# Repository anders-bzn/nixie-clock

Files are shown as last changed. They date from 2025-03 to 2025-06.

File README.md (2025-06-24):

# About the Nixie Clock

This is a clock powered by a Raspberry Pi Zero W. It fetches current time by 
NTP and must be connected to a WiFi network to display the time.

The time is displayed on six IN-14 nixie tubes driven by six 74141. No 
multiplexing! The intensity can be adjusted by PWM.

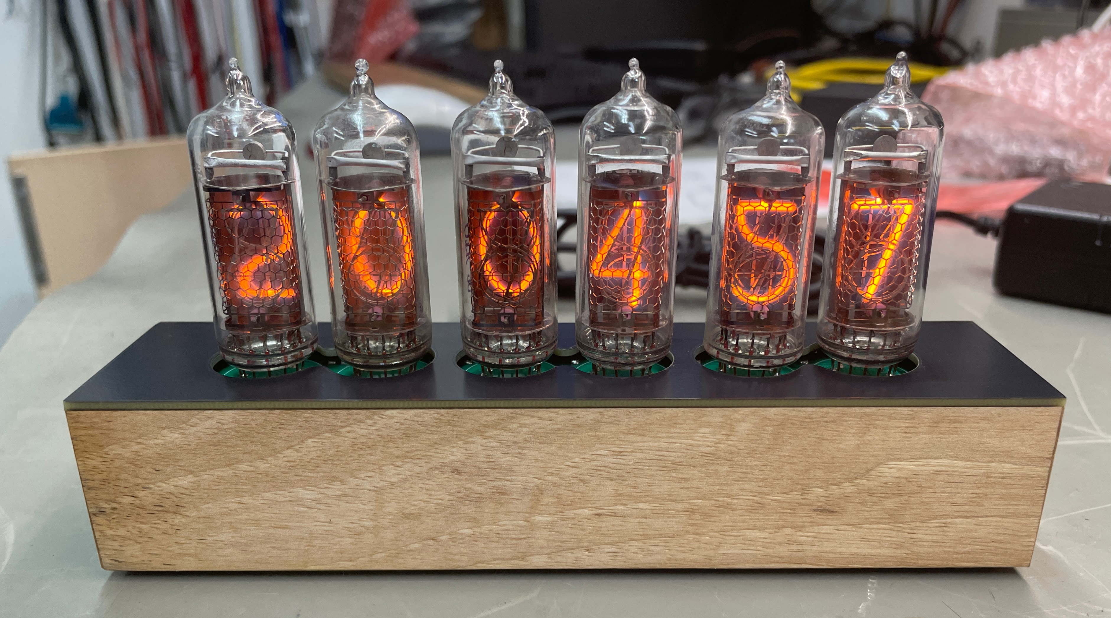
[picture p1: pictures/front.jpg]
Clock front

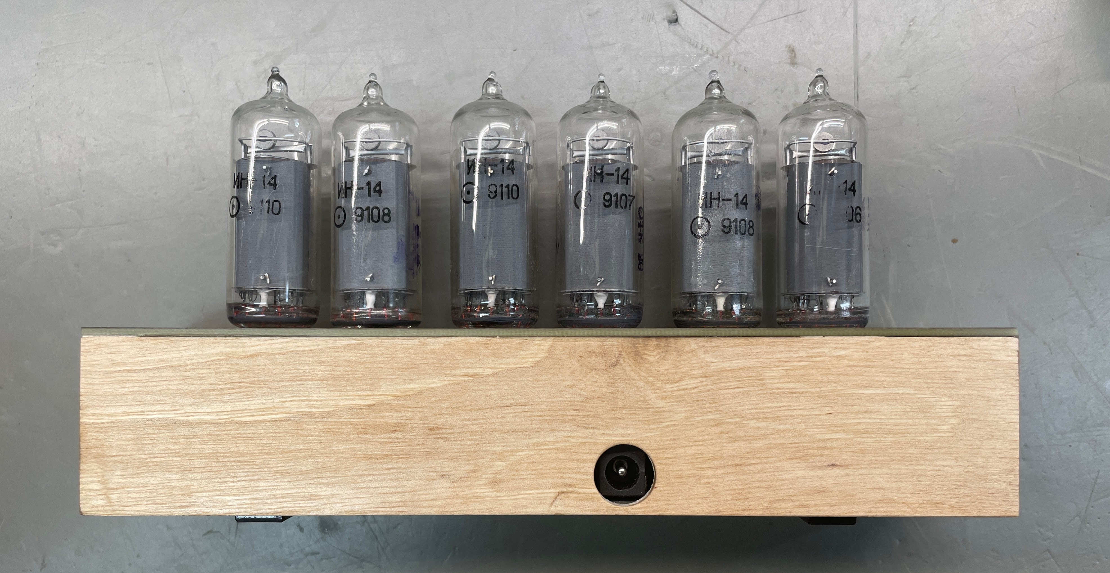
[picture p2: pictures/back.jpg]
Clock back

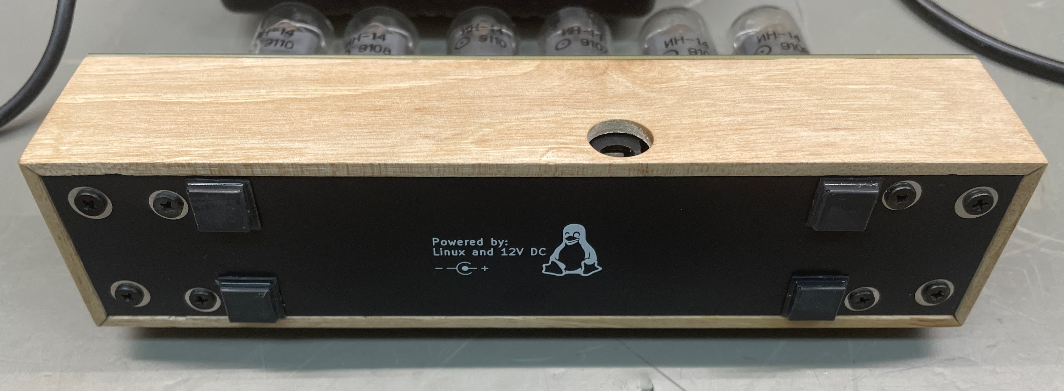
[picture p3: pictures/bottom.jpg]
Clock bottom


## PCB's 
There are in total five PCB's in this project. All boards are drawn with KiCad 8.0.

### Board nixie-bottom
Bottom lid, no electrical function.

### Board nixie-clock
The main board, it hold gpio-expanders and driver IC's for the tubes. It
also connects to the PSU board, Raspberry Pi and the nixie tube board.

### Board nixie-clock-psu
Power supply board, creates 5V DC and 170V DC from 12V DC. The 170V is created by a step up converter built using a MAX1771 IC. The 5V is created by a integrated switched regulator.

### Board nixie-clock-tubes
Upper board on which all tubes are mounted.

### Board nixie-top
Top lid, no electrical function.

### Software
The clocks software is written in Python. It's just a simple poll loop that set the new time on gpio's on the gpio-expanders every time the second changes. It's started as a systemd service at boot time.

To install the software on the Raspberry Pi, copy the [./sw](sw/) folder to the Raspberry Pi and install the software by:

```
$ sudo ./clock-setup.sh
$ sudo reboot
```

NOTE: [./sw/timesyncd.conf](sw/timesyncd.conf) is an example.

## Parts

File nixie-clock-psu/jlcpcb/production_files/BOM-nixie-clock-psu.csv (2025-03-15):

Comment | Designator | Footprint | LCSC | Quantity
R-78B5.0-0.5 | U2 | 78xx-05A |  | 1
MAX1771xSA | U1 | SO-8_3.9x4.9mm_P1.27mm |  | 1
0R10 | R3 | R_1206_3216Metric |  | 1
13k3 | R2 | R_1206_3216Metric |  | 1
1M5 | R1 | R_1206_3216Metric |  | 1
IRF644 | Q1 | TO-263-2 |  | 1
100u | L2 | L_Sunlord_SWPA8040S |  | 1
4u7 | L1 | L_Changjiang_FNR4030S |  | 1
ES2F | D2 | D_SMB |  | 1
1n | C11 | C_0805_2012Metric_Pad1.18x1.45mm_HandSolder |  | 1
100n | C10 | C_0805_2012Metric_Pad1.18x1.45mm_HandSolder |  | 1
100n | C9 | C_0805_2012Metric_Pad1.18x1.45mm_HandSolder |  | 1
100n | C8 | C_0805_2012Metric_Pad1.18x1.45mm_HandSolder |  | 1
10uF/250V | C7 | CP_Elec_10x12.5 |  | 1
330uF/16V | C6 | CP_Elec_6.3x7.7 |  | 1
100uF/10V | C5 | CP_Elec_5x5.3 |  | 1
12V DC | J2 | BarrelJack_GCT_DCJ200-10-A_Horizontal |  | 1
10u | C4 | C_0805_2012Metric_Pad1.18x1.45mm_HandSolder |  | 1
1n | C3 | C_0805_2012Metric_Pad1.18x1.45mm_HandSolder |  | 1
10u | C2 | C_0805_2012Metric_Pad1.18x1.45mm_HandSolder |  | 1
10u | C1 | C_0805_2012Metric_Pad1.18x1.45mm_HandSolder |  | 1
Conn_01x04_Pin | J1 | PinSocket_1x04_P2.54mm_Vertical |  | 1

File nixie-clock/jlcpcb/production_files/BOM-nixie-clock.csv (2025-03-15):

Comment | Designator | Footprint | LCSC | Quantity
1k | R10 | R_0805_2012Metric_Pad1.20x1.40mm_HandSolder |  | 1
1k | R9 | R_1206_3216Metric_Pad1.30x1.75mm_HandSolder |  | 1
220k | R8 | R_1206_3216Metric_Pad1.30x1.75mm_HandSolder |  | 1
PMBTA92 | Q2 | SOT-23 |  | 1
PMBTA42 | Q1 | SOT-23 |  | 1
100n | C9 | C_0805_2012Metric_Pad1.18x1.45mm_HandSolder |  | 1
100n | C8 | C_0805_2012Metric_Pad1.18x1.45mm_HandSolder |  | 1
74141 | U6 | DIP-16_W7.62mm |  | 1
Conn_02x05_Odd_Even | J7 | PinHeader_2x05_P2.00mm_Vertical |  | 1
100n | C5 | C_0805_2012Metric_Pad1.18x1.45mm_HandSolder |  | 1
Conn_02x05_Odd_Even | J9 | PinHeader_2x05_P2.00mm_Vertical |  | 1
Conn_02x05_Odd_Even | J8 | PinHeader_2x05_P2.00mm_Vertical |  | 1
Conn_02x05_Odd_Even | J6 | PinHeader_2x05_P2.00mm_Vertical |  | 1
Conn_02x05_Odd_Even | J5 | PinHeader_2x05_P2.00mm_Vertical |  | 1
Conn_02x02_Odd_Even | J4 | PinHeader_2x02_P2.00mm_Vertical |  | 1
Conn_02x05_Odd_Even | J3 | PinHeader_2x05_P2.00mm_Vertical |  | 1
Conn_01x04_Pin | J2 | PinHeader_1x04_P2.54mm_Vertical |  | 1
TCA9406DC | U4 | SSOP-8_2.95x2.8mm_P0.65mm |  | 1
4k7 | R7 | R_0805_2012Metric_Pad1.20x1.40mm_HandSolder |  | 1
4k7 | R6 | R_0805_2012Metric_Pad1.20x1.40mm_HandSolder |  | 1
MCP23017_SO | U11 | SSOP-28_5.3x10.2mm_P0.65mm |  | 1
74141 | U8 | DIP-16_W7.62mm |  | 1
74141 | U7 | DIP-16_W7.62mm |  | 1
100n | C10 | C_0805_2012Metric_Pad1.18x1.45mm_HandSolder |  | 1
100n | C7 | C_0805_2012Metric_Pad1.18x1.45mm_HandSolder |  | 1
100n | C6 | C_0805_2012Metric_Pad1.18x1.45mm_HandSolder |  | 1
MCP23017_SO | U1 | SSOP-28_5.3x10.2mm_P0.65mm |  | 1
74141 | U5 | DIP-16_W7.62mm |  | 1
74141 | U3 | DIP-16_W7.62mm |  | 1
74141 | U2 | DIP-16_W7.62mm |  | 1
4k7 | R5 | R_0805_2012Metric_Pad1.20x1.40mm_HandSolder |  | 1
4k7 | R4 | R_0805_2012Metric_Pad1.20x1.40mm_HandSolder |  | 1
100n | C4 | C_0805_2012Metric_Pad1.18x1.45mm_HandSolder |  | 1
100n | C3 | C_0805_2012Metric_Pad1.18x1.45mm_HandSolder |  | 1
100n | C2 | C_0805_2012Metric_Pad1.18x1.45mm_HandSolder |  | 1
100n | C1 | C_0805_2012Metric_Pad1.18x1.45mm_HandSolder |  | 1
Raspberry_Pi_2_3 | J1 | Raspberry_Pi_Zero_Socketed_THT_FaceDown_MountingHoles |  | 1

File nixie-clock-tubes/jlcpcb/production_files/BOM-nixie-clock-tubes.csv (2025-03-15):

Comment | Designator | Footprint | LCSC | Quantity
~ | N6 | IN-14 |  | 1
~ | N5 | IN-14 |  | 1
~ | N4 | IN-14 |  | 1
~ | N3 | IN-14 |  | 1
~ | N2 | IN-14 |  | 1
~ | N1 | IN-14 |  | 1
Conn_02x02_Odd_Even | J7 | PinSocket_2x02_P2.00mm_Vertical |  | 1
Conn_02x05_Odd_Even | J6 | PinSocket_2x05_P2.00mm_Vertical |  | 1
Conn_02x05_Odd_Even | J5 | PinSocket_2x05_P2.00mm_Vertical |  | 1
Conn_02x05_Odd_Even | J4 | PinSocket_2x05_P2.00mm_Vertical |  | 1
Conn_02x05_Odd_Even | J3 | PinSocket_2x05_P2.00mm_Vertical |  | 1
Conn_02x05_Odd_Even | J2 | PinSocket_2x05_P2.00mm_Vertical |  | 1
Conn_02x05_Odd_Even | J1 | PinSocket_2x05_P2.00mm_Vertical |  | 1
2k2 | R6 | R_1206_3216Metric |  | 1
2k2 | R5 | R_1206_3216Metric |  | 1
2k2 | R4 | R_1206_3216Metric |  | 1
2k2 | R3 | R_1206_3216Metric |  | 1
2k2 | R2 | R_1206_3216Metric |  | 1
2k2 | R1 | R_1206_3216Metric |  | 1

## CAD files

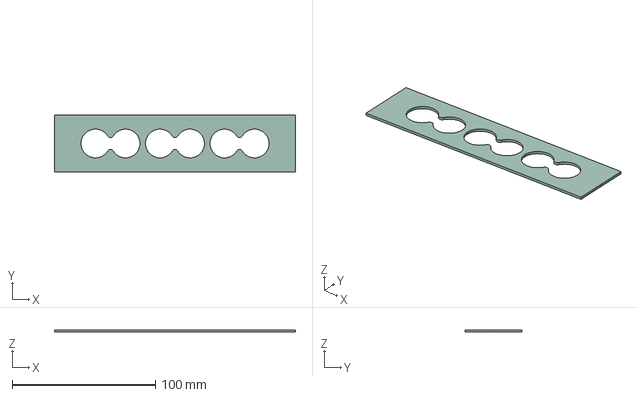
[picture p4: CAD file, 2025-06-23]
nixie-top/nixie-top.step
168.0 x 40.0 x 1.60 mm

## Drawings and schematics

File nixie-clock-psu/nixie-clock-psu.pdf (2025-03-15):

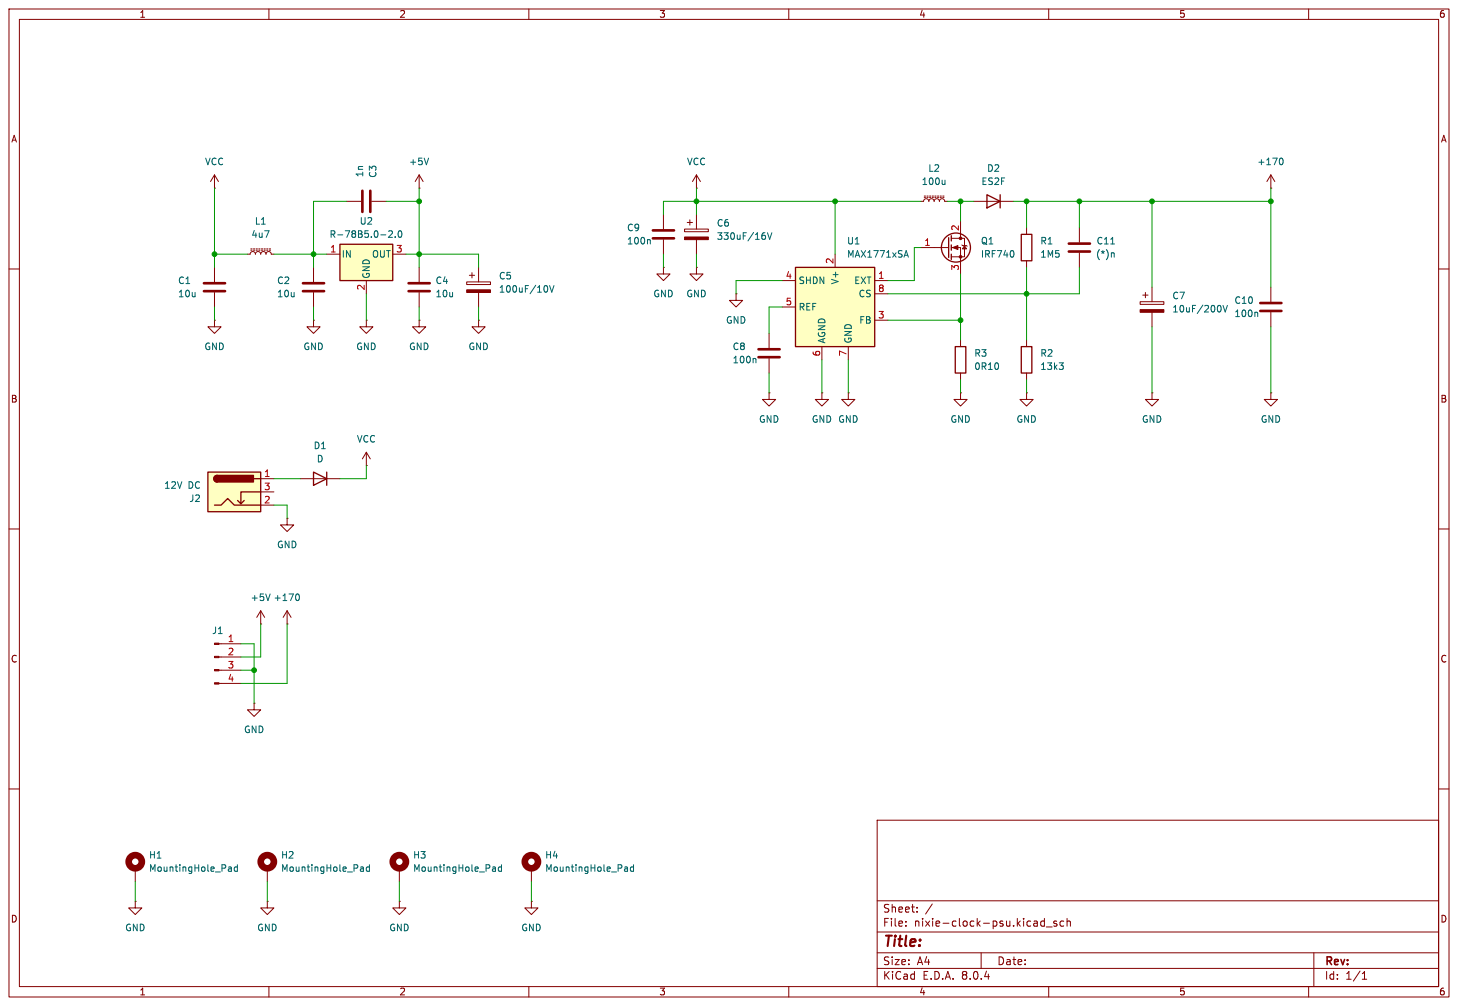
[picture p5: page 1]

2 FB 3 SHDN 4 REF 5 AGND

Id: 1/1 Title: File: nixie-clock-psu.kicad_sch Sheet: /

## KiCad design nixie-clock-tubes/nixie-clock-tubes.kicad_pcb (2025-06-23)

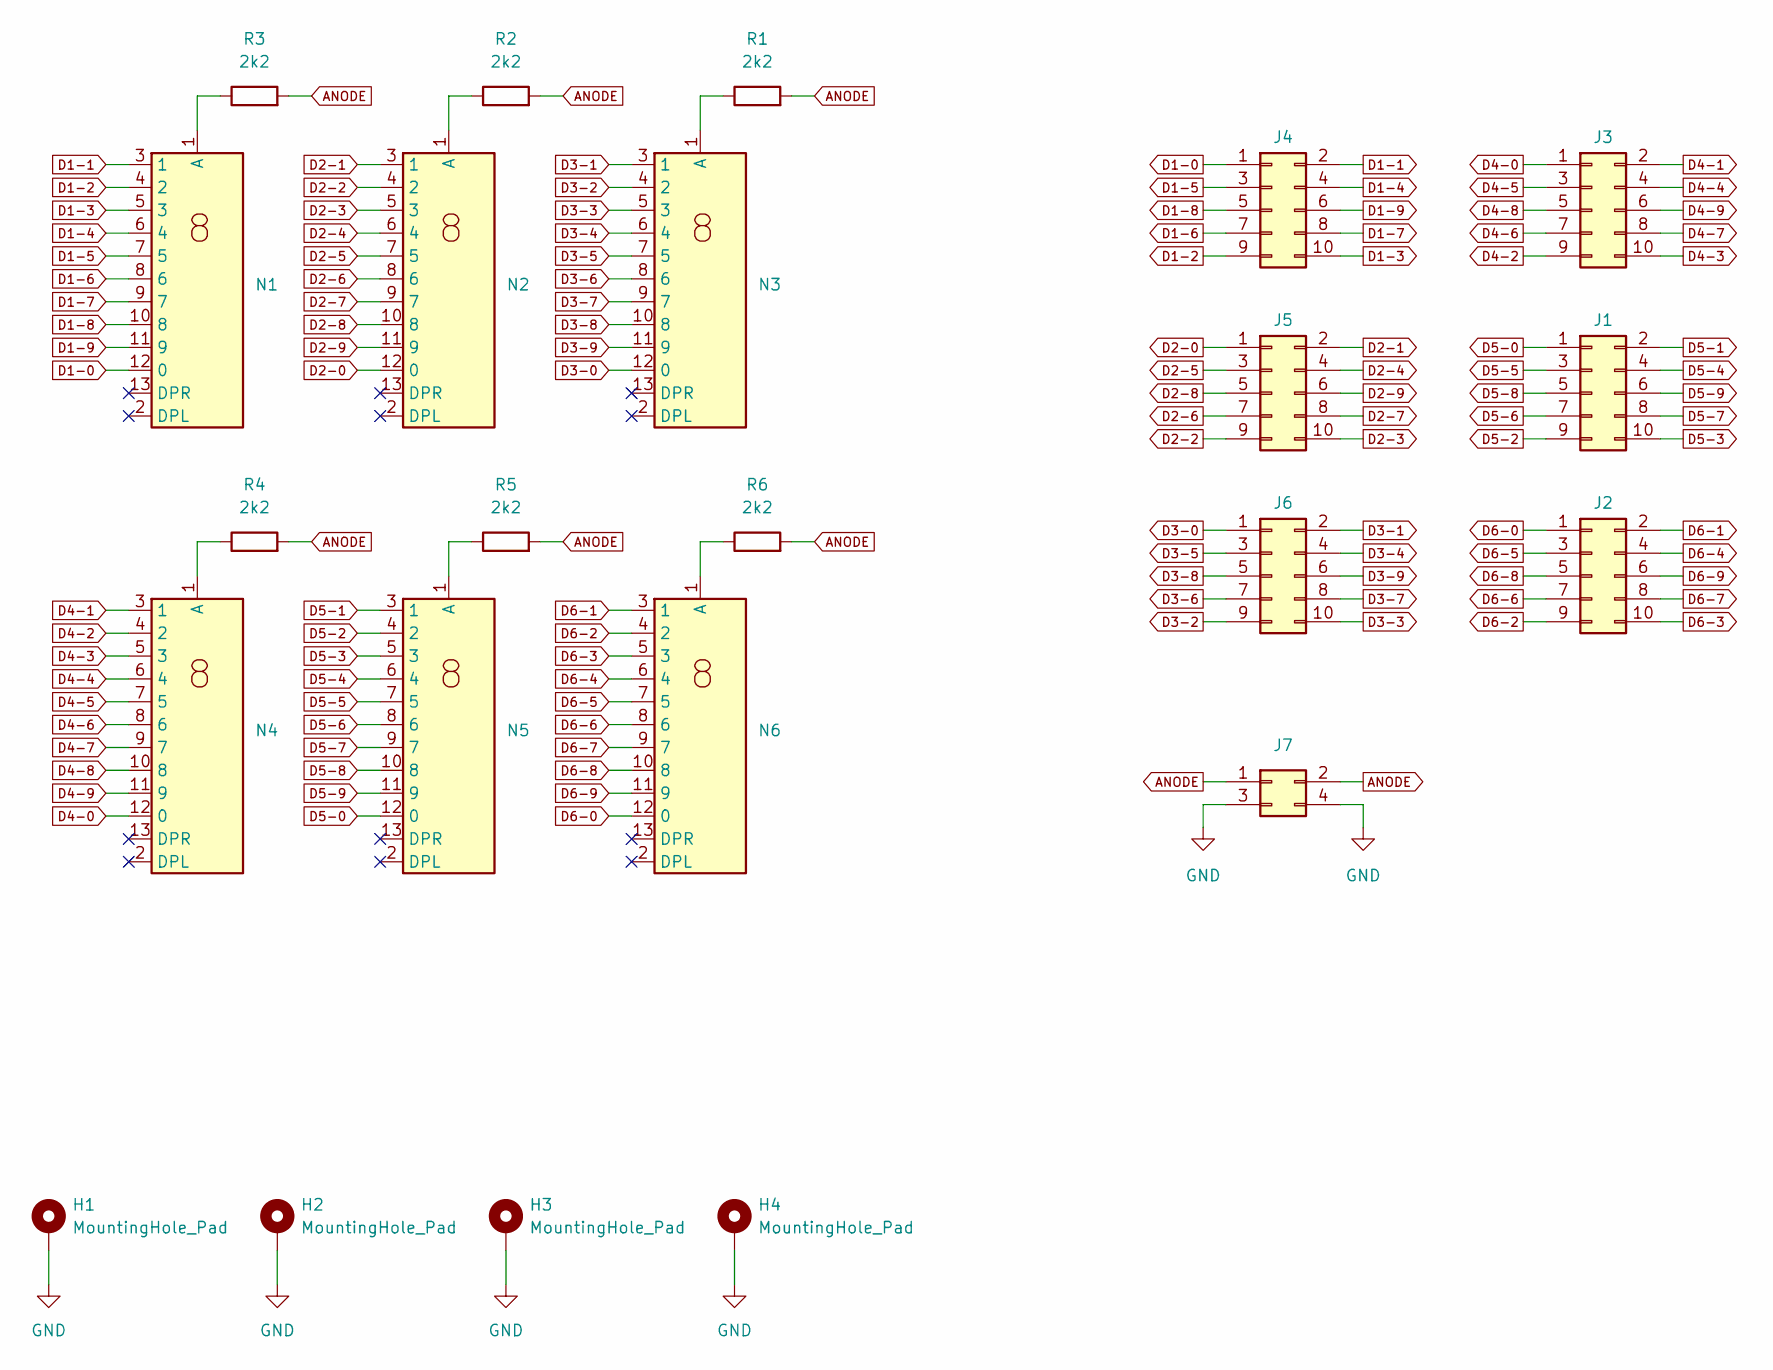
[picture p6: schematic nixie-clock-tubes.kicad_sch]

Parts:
H1, H2, H3, H4: MountingHole_Pad; MountingHole_2.7mm_M2.5_DIN965_Pad
J1, J2, J3, J4, J5, J6: Conn_02x05_Odd_Even; PinSocket_2x05_P2.00mm_Vertical
J7: Conn_02x02_Odd_Even; PinSocket_2x02_P2.00mm_Vertical
N1, N2, N3, N4, N5, N6: IN-14
R1, R2, R3, R4, R5, R6: 2k2; R_1206_3216Metric

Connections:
ANODE: J7.1, J7.2, R1.2, R2.2, R3.2, R4.2, R5.2, R6.2
D1-0: J4.1, N1.12 (0)
D1-1: J4.2, N1.3 (1)
D1-2: J4.9, N1.4 (2)
D1-3: J4.10, N1.5 (3)
D1-4: J4.4, N1.6 (4)
D1-5: J4.3, N1.7 (5)
D1-6: J4.7, N1.8 (6)
D1-7: J4.8, N1.9 (7)
D1-8: J4.5, N1.10 (8)
D1-9: J4.6, N1.11 (9)
D2-0: J5.1, N2.12 (0)
D2-1: J5.2, N2.3 (1)
D2-2: J5.9, N2.4 (2)
D2-3: J5.10, N2.5 (3)
D2-4: J5.4, N2.6 (4)
D2-5: J5.3, N2.7 (5)
D2-6: J5.7, N2.8 (6)
D2-7: J5.8, N2.9 (7)
D2-8: J5.5, N2.10 (8)
D2-9: J5.6, N2.11 (9)
D3-0: J6.1, N3.12 (0)
D3-1: J6.2, N3.3 (1)
D3-2: J6.9, N3.4 (2)
D3-3: J6.10, N3.5 (3)
D3-4: J6.4, N3.6 (4)
D3-5: J6.3, N3.7 (5)
D3-6: J6.7, N3.8 (6)
D3-7: J6.8, N3.9 (7)
D3-8: J6.5, N3.10 (8)
D3-9: J6.6, N3.11 (9)
D4-0: J3.1, N4.12 (0)
D4-1: J3.2, N4.3 (1)
D4-2: J3.9, N4.4 (2)
D4-3: J3.10, N4.5 (3)
D4-4: J3.4, N4.6 (4)
D4-5: J3.3, N4.7 (5)
D4-6: J3.7, N4.8 (6)
D4-7: J3.8, N4.9 (7)
D4-8: J3.5, N4.10 (8)
D4-9: J3.6, N4.11 (9)
D5-0: J1.1, N5.12 (0)
D5-1: J1.2, N5.3 (1)
D5-2: J1.9, N5.4 (2)
D5-3: J1.10, N5.5 (3)
D5-4: J1.4, N5.6 (4)
D5-5: J1.3, N5.7 (5)
D5-6: J1.7, N5.8 (6)
D5-7: J1.8, N5.9 (7)
D5-8: J1.5, N5.10 (8)
D5-9: J1.6, N5.11 (9)
D6-0: J2.1, N6.12 (0)
D6-1: J2.2, N6.3 (1)
D6-2: J2.9, N6.4 (2)
D6-3: J2.10, N6.5 (3)
D6-4: J2.4, N6.6 (4)
D6-5: J2.3, N6.7 (5)
D6-6: J2.7, N6.8 (6)
D6-7: J2.8, N6.9 (7)
D6-8: J2.5, N6.10 (8)
D6-9: J2.6, N6.11 (9)
GND: H1.1, H2.1, H3.1, H4.1, J7.3, J7.4
unnamed: N1.1 (A), R3.1
unnamed: N2.1 (A), R2.1
unnamed: N3.1 (A), R1.1
unnamed: N4.1 (A), R4.1
unnamed: N5.1 (A), R5.1
unnamed: N6.1 (A), R6.1

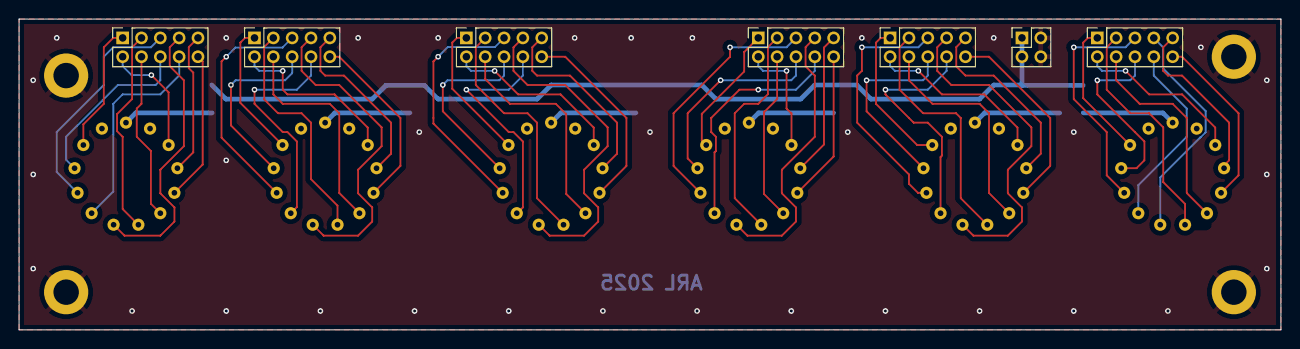
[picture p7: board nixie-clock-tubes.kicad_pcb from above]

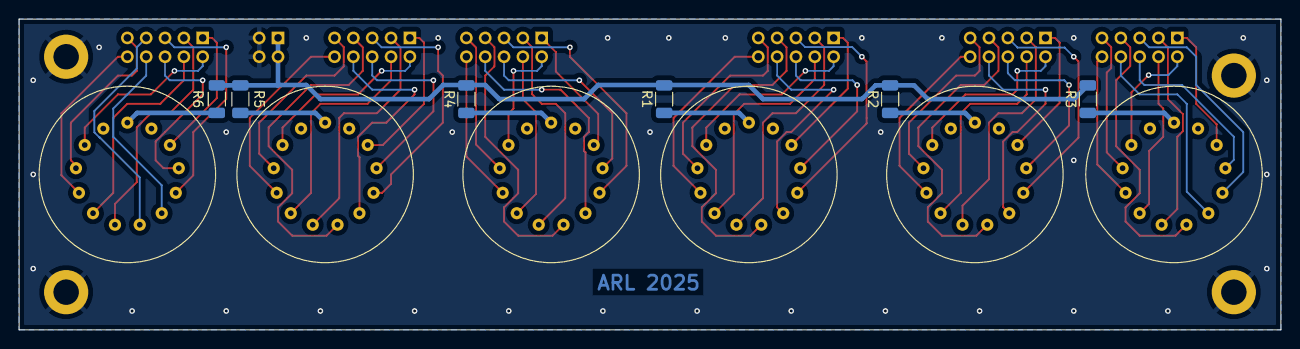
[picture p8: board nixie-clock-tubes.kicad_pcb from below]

Board: 2 copper layers, 134.0 x 33.0 mm, 23 parts (12 on the bottom side), 68 nets.

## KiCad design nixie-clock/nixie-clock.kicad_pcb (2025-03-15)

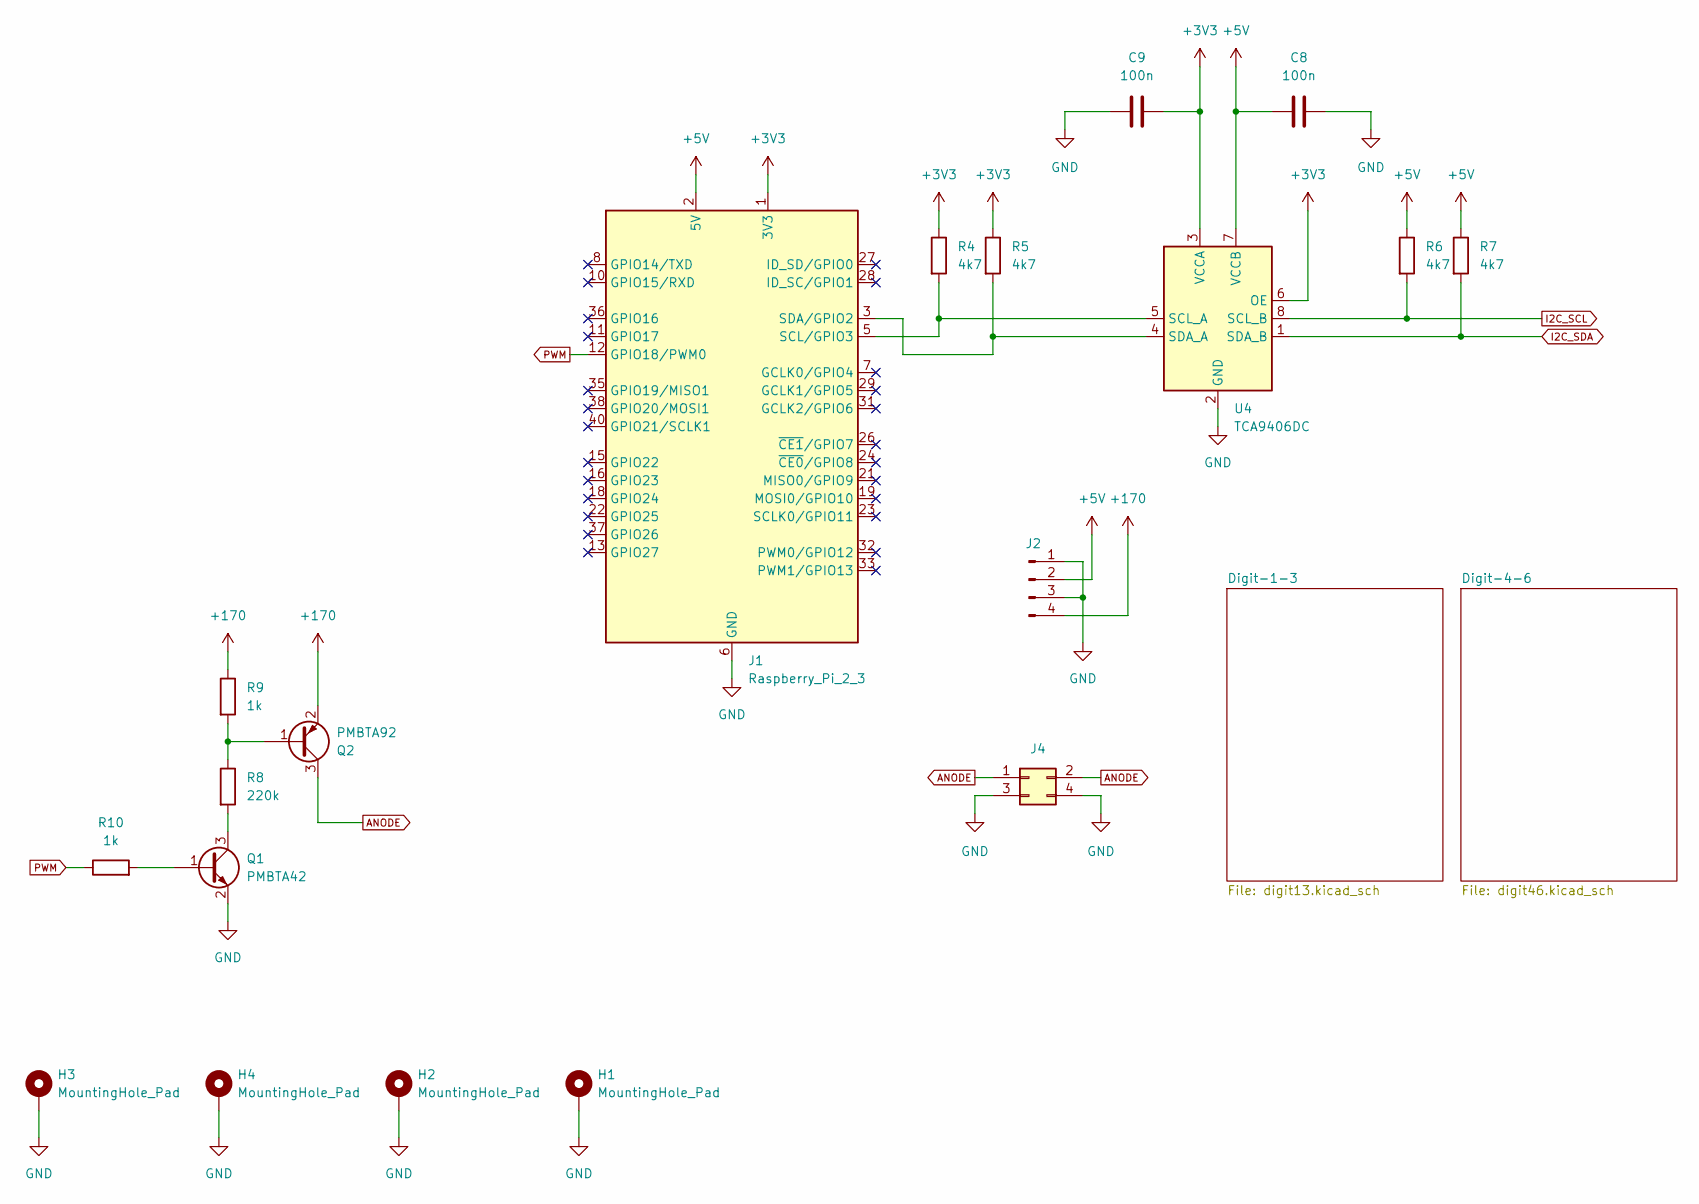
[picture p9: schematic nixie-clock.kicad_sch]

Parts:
C8, C9: 100n; C_0805_2012Metric_Pad1.18x1.45mm_HandSolder
H1, H2, H3, H4: MountingHole_Pad; MountingHole_2.7mm_M2.5_DIN965_Pad
J1: Raspberry_Pi_2_3; Raspberry_Pi_Zero_Socketed_THT_FaceDown_MountingHoles
J2: Conn_01x04_Pin; PinHeader_1x04_P2.54mm_Vertical
J4: Conn_02x02_Odd_Even; PinHeader_2x02_P2.00mm_Vertical
Q1: PMBTA42; SOT-23
Q2: PMBTA92; SOT-23
R4, R5, R6, R7: 4k7; R_0805_2012Metric_Pad1.20x1.40mm_HandSolder
R8: 220k; R_1206_3216Metric_Pad1.30x1.75mm_HandSolder
R9: 1k; R_1206_3216Metric_Pad1.30x1.75mm_HandSolder
R10: 1k; R_0805_2012Metric_Pad1.20x1.40mm_HandSolder
U4: TCA9406DC; SSOP-8_2.95x2.8mm_P0.65mm

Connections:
+3V3: C9.1, J1.1 (3V3), J1.17 (3V3), R4.1, R5.1, U4.3 (VCCA), U4.6 (OE)
+5V: C8.1, J1.2 (5V), J1.4 (5V), J2.2, R6.1, R7.1, U4.7 (VCCB); also elsewhere on the board
+170: J2.4, Q2.2 (E), R9.1
ANODE: J4.1, J4.2, Q2.3 (C)
GND: C8.2, C9.2, H1.1, H2.1, H3.1, H4.1, J1.6 (GND), J1.9 (GND), J1.14 (GND), J1.20 (GND), J1.25 (GND), J1.30 (GND), J1.34 (GND), J1.39 (GND), J2.1, J2.3, J4.3, J4.4, Q1.2 (E), U4.2 (GND); also elsewhere on the board
I2C_SCL: R6.2, U4.8 (SCL_B); also elsewhere on the board
I2C_SDA: R7.2, U4.1 (SDA_B); also elsewhere on the board
unnamed: J1.5 (SCL/GPIO3), R4.2, U4.5 (SCL_A)
unnamed: J1.3 (SDA/GPIO2), R5.2, U4.4 (SDA_A)
unnamed: Q1.1 (B), R10.2
unnamed: Q1.3 (C), R8.2
unnamed: Q2.1 (B), R8.1, R9.2
PWM: J1.12 (GPIO18/PWM0), R10.1

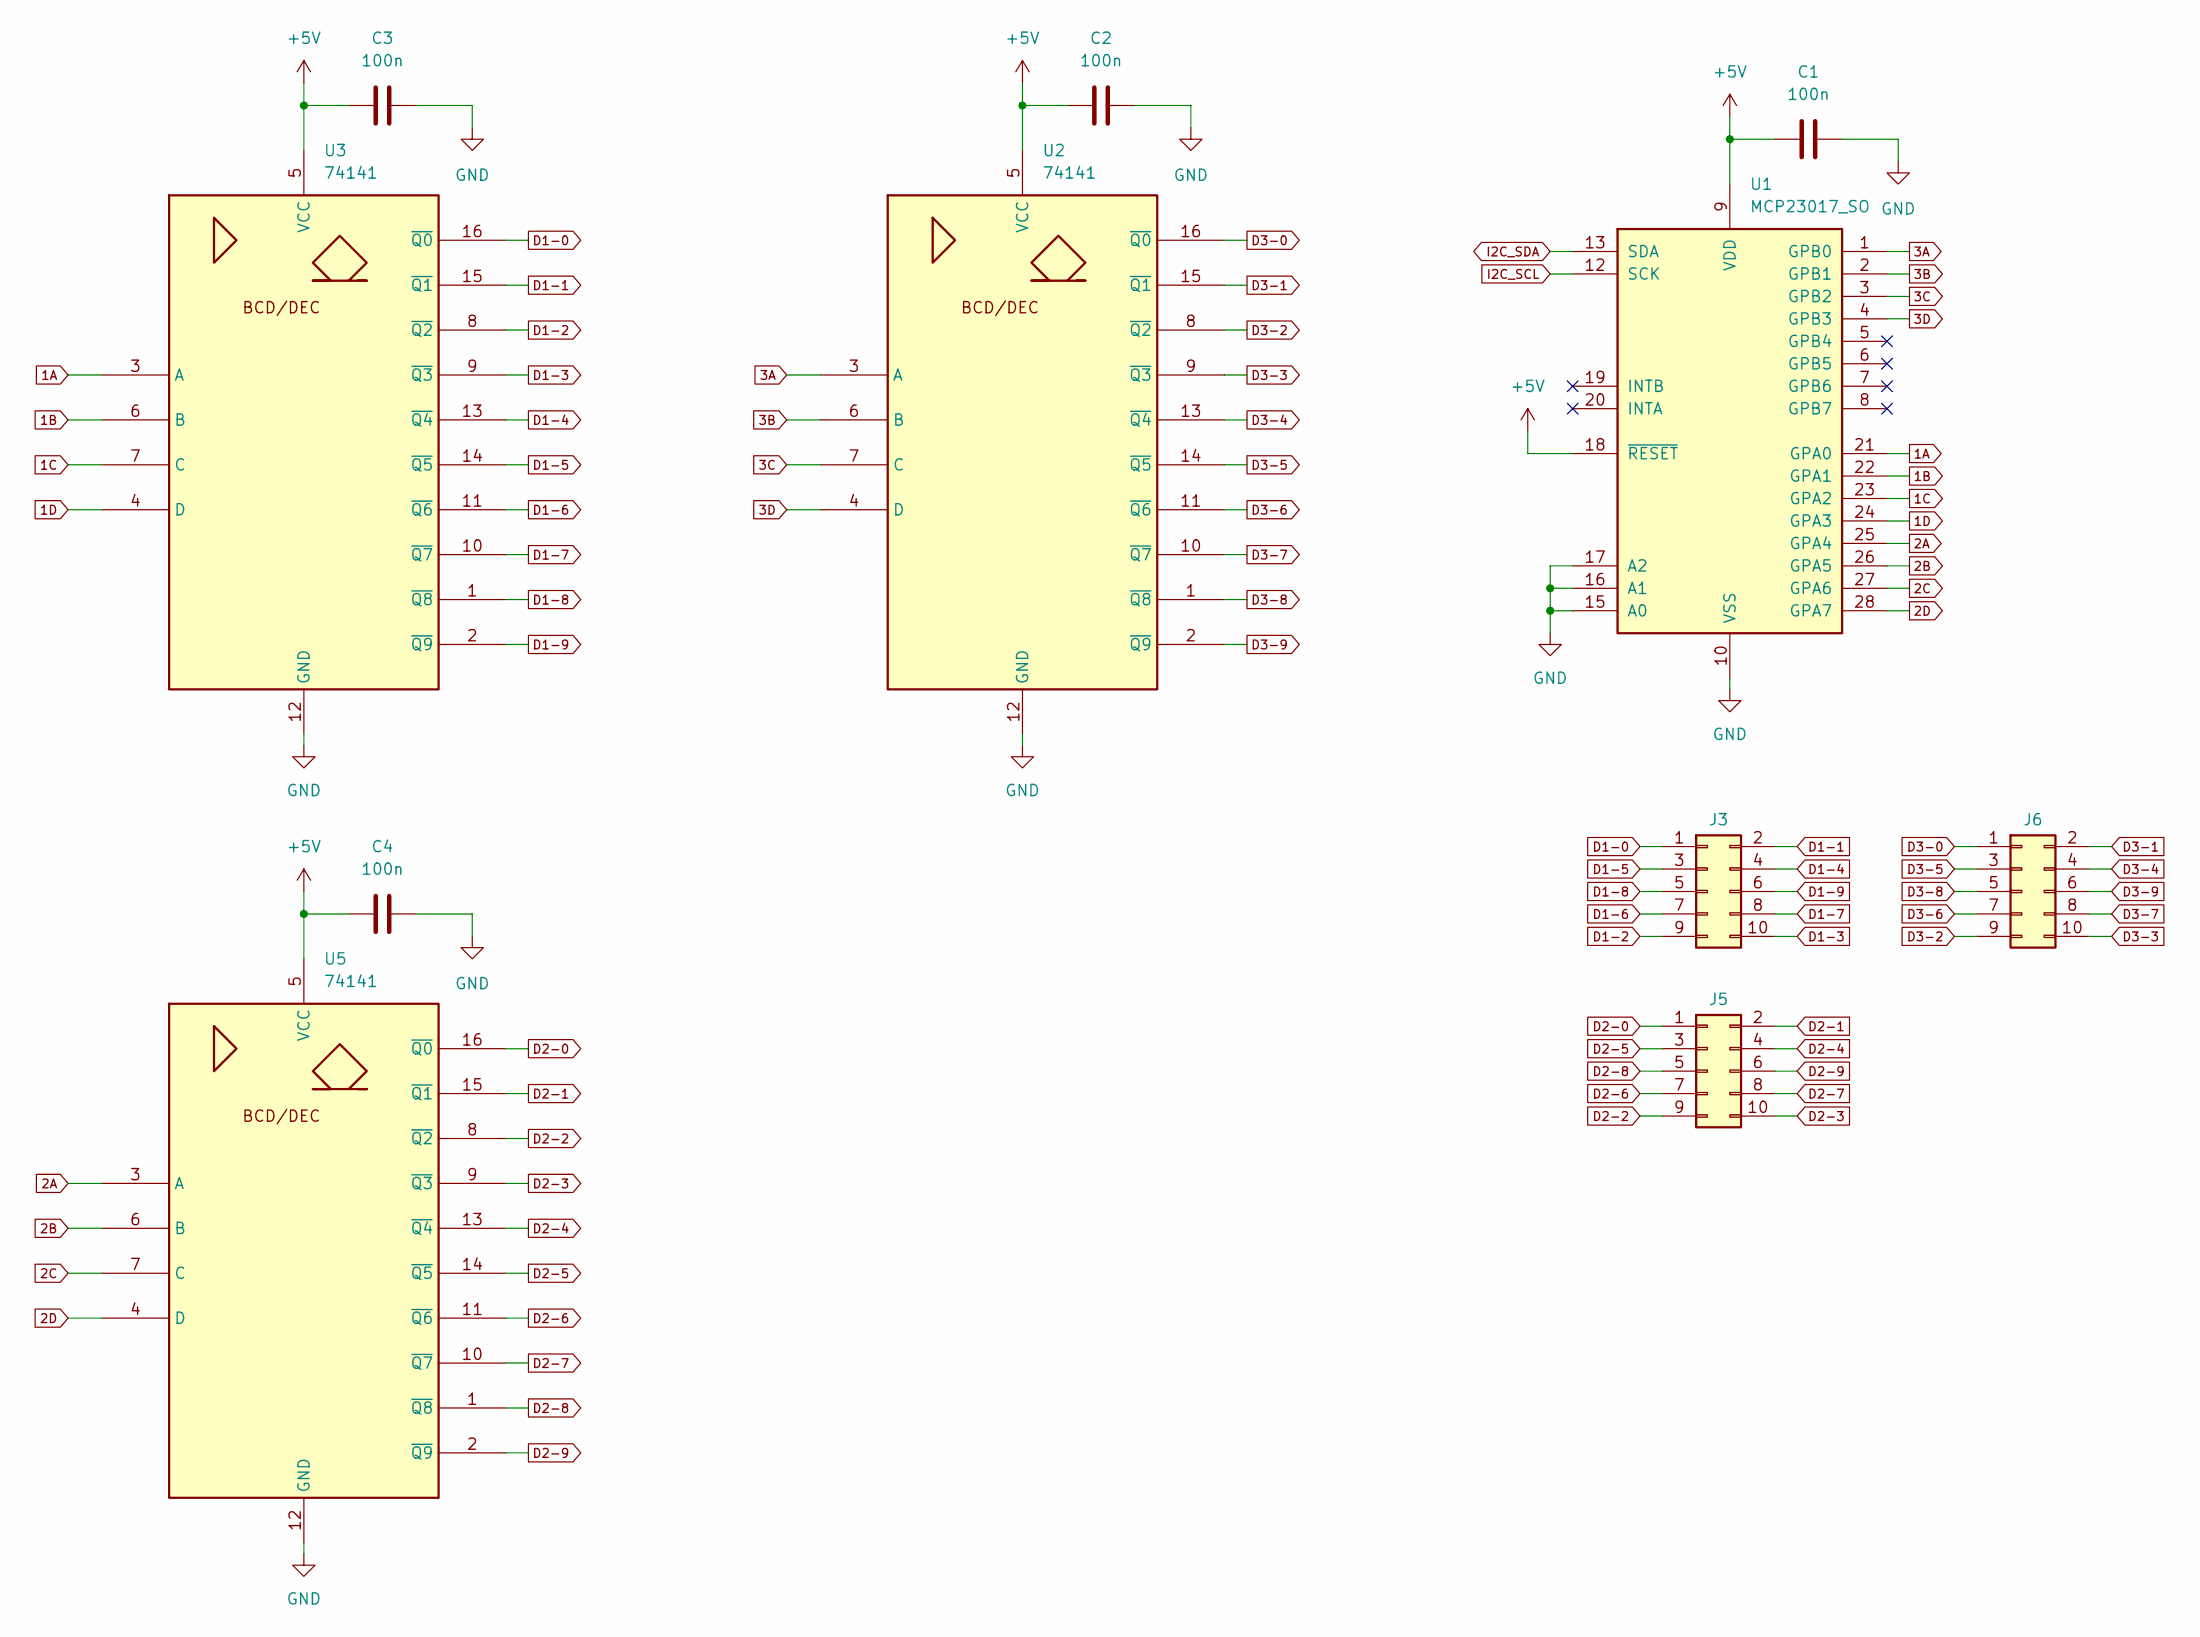
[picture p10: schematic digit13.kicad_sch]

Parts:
C1, C2, C3, C4: 100n; C_0805_2012Metric_Pad1.18x1.45mm_HandSolder
J3, J5, J6: Conn_02x05_Odd_Even; PinHeader_2x05_P2.00mm_Vertical
U1: MCP23017_SO; SSOP-28_5.3x10.2mm_P0.65mm
U2, U3, U5: 74141; DIP-16_W7.62mm

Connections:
1A: U1.21 (GPA0), U3.3 (A)
1B: U1.22 (GPA1), U3.6 (B)
1C: U1.23 (GPA2), U3.7 (C)
1D: U1.24 (GPA3), U3.4 (D)
2A: U1.25 (GPA4), U5.3 (A)
2B: U1.26 (GPA5), U5.6 (B)
2C: U1.27 (GPA6), U5.7 (C)
2D: U1.28 (GPA7), U5.4 (D)
3A: U1.1 (GPB0), U2.3 (A)
3B: U1.2 (GPB1), U2.6 (B)
3C: U1.3 (GPB2), U2.7 (C)
3D: U1.4 (GPB3), U2.4 (D)
+5V: C1.1, C2.1, C3.1, C4.1, U1.9 (VDD), U1.18 (~RESET), U2.5 (VCC), U3.5 (VCC), U5.5 (VCC); also elsewhere on the board
D1-0: J3.1, U3.16 (~Q0)
D1-1: J3.2, U3.15 (~Q1)
D1-2: J3.9, U3.8 (~Q2)
D1-3: J3.10, U3.9 (~Q3)
D1-4: J3.4, U3.13 (~Q4)
D1-5: J3.3, U3.14 (~Q5)
D1-6: J3.7, U3.11 (~Q6)
D1-7: J3.8, U3.10 (~Q7)
D1-8: J3.5, U3.1 (~Q8)
D1-9: J3.6, U3.2 (~Q9)
D2-0: J5.1, U5.16 (~Q0)
D2-1: J5.2, U5.15 (~Q1)
D2-2: J5.9, U5.8 (~Q2)
D2-3: J5.10, U5.9 (~Q3)
D2-4: J5.4, U5.13 (~Q4)
D2-5: J5.3, U5.14 (~Q5)
D2-6: J5.7, U5.11 (~Q6)
D2-7: J5.8, U5.10 (~Q7)
D2-8: J5.5, U5.1 (~Q8)
D2-9: J5.6, U5.2 (~Q9)
D3-0: J6.1, U2.16 (~Q0)
D3-1: J6.2, U2.15 (~Q1)
D3-2: J6.9, U2.8 (~Q2)
D3-3: J6.10, U2.9 (~Q3)
D3-4: J6.4, U2.13 (~Q4)
D3-5: J6.3, U2.14 (~Q5)
D3-6: J6.7, U2.11 (~Q6)
D3-7: J6.8, U2.10 (~Q7)
D3-8: J6.5, U2.1 (~Q8)
D3-9: J6.6, U2.2 (~Q9)
GND: C1.2, C2.2, C3.2, C4.2, U1.10 (VSS), U1.15 (A0), U1.16 (A1), U1.17 (A2), U2.12 (GND), U3.12 (GND), U5.12 (GND); also elsewhere on the board
I2C_SCL: U1.12 (SCK); also elsewhere on the board
I2C_SDA: U1.13 (SDA); also elsewhere on the board

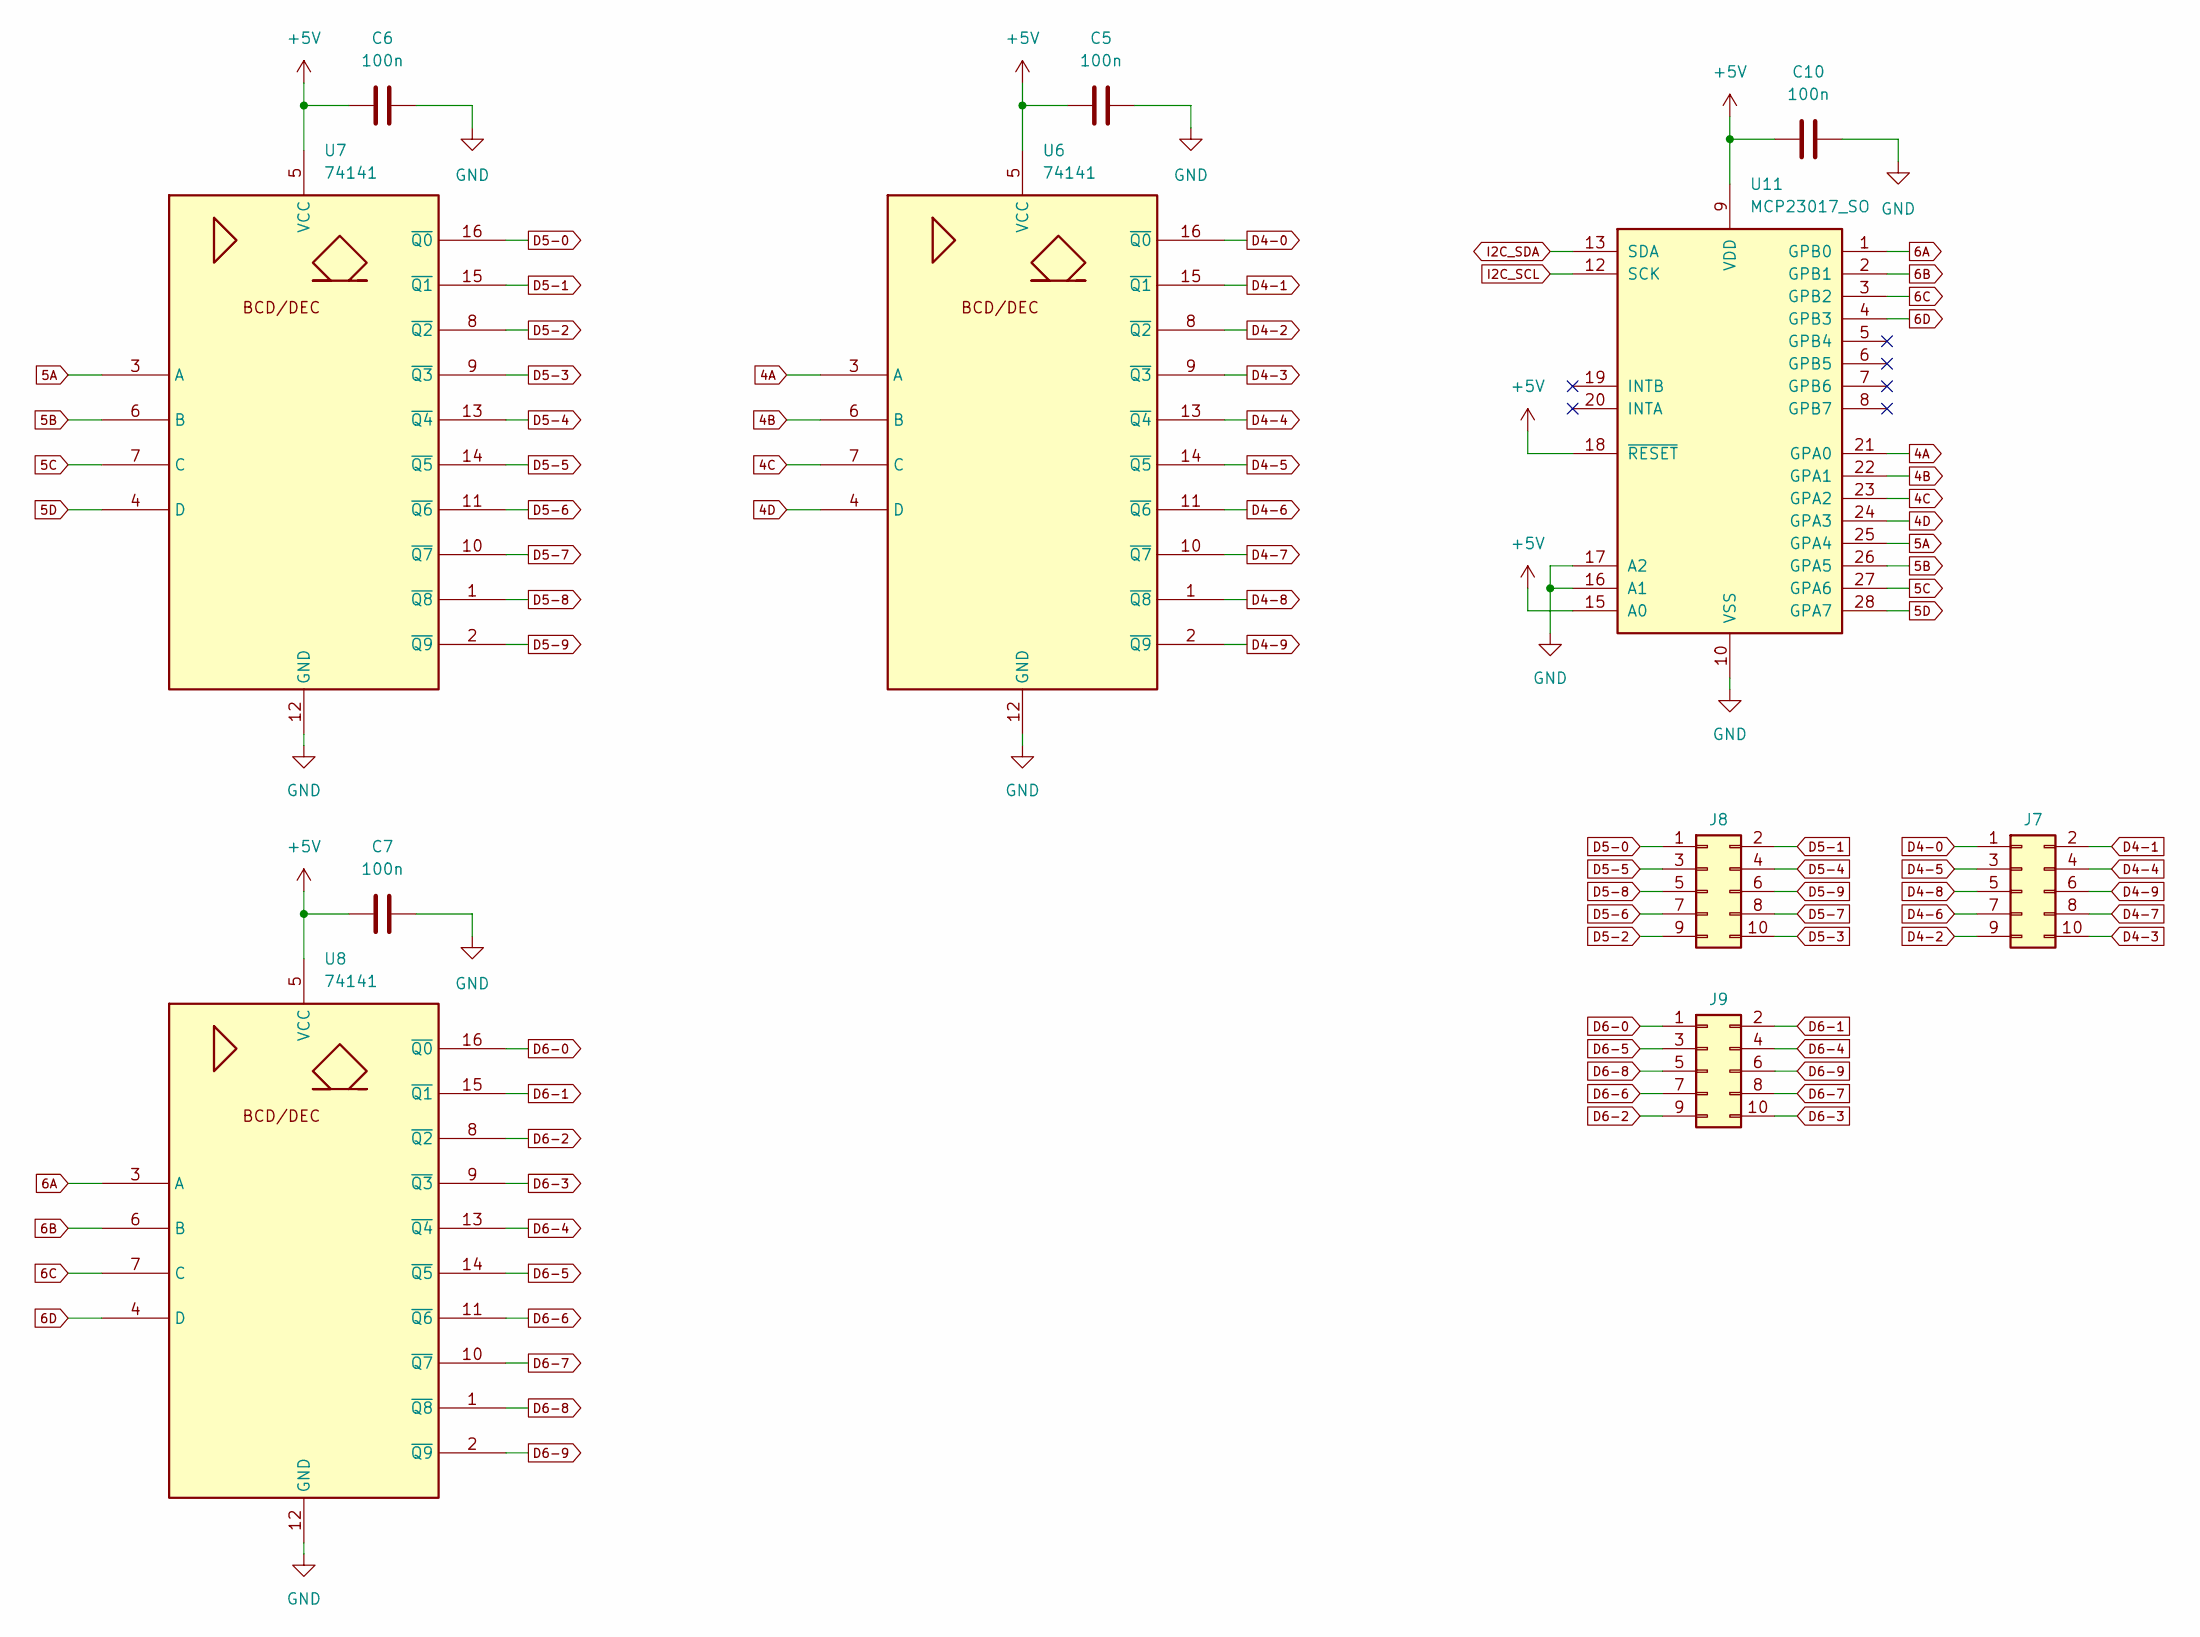
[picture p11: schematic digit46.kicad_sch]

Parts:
C5, C6, C7, C10: 100n; C_0805_2012Metric_Pad1.18x1.45mm_HandSolder
J7, J8, J9: Conn_02x05_Odd_Even; PinHeader_2x05_P2.00mm_Vertical
U6, U7, U8: 74141; DIP-16_W7.62mm
U11: MCP23017_SO; SSOP-28_5.3x10.2mm_P0.65mm

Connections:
4A: U6.3 (A), U11.21 (GPA0)
4B: U6.6 (B), U11.22 (GPA1)
4C: U6.7 (C), U11.23 (GPA2)
4D: U6.4 (D), U11.24 (GPA3)
5A: U7.3 (A), U11.25 (GPA4)
5B: U7.6 (B), U11.26 (GPA5)
5C: U7.7 (C), U11.27 (GPA6)
5D: U7.4 (D), U11.28 (GPA7)
6A: U8.3 (A), U11.1 (GPB0)
6B: U8.6 (B), U11.2 (GPB1)
6C: U8.7 (C), U11.3 (GPB2)
6D: U8.4 (D), U11.4 (GPB3)
+5V: C5.1, C6.1, C7.1, C10.1, U6.5 (VCC), U7.5 (VCC), U8.5 (VCC), U11.9 (VDD), U11.15 (A0), U11.18 (~RESET); also elsewhere on the board
D4-0: J7.1, U6.16 (~Q0)
D4-1: J7.2, U6.15 (~Q1)
D4-2: J7.9, U6.8 (~Q2)
D4-3: J7.10, U6.9 (~Q3)
D4-4: J7.4, U6.13 (~Q4)
D4-5: J7.3, U6.14 (~Q5)
D4-6: J7.7, U6.11 (~Q6)
D4-7: J7.8, U6.10 (~Q7)
D4-8: J7.5, U6.1 (~Q8)
D4-9: J7.6, U6.2 (~Q9)
D5-0: J8.1, U7.16 (~Q0)
D5-1: J8.2, U7.15 (~Q1)
D5-2: J8.9, U7.8 (~Q2)
D5-3: J8.10, U7.9 (~Q3)
D5-4: J8.4, U7.13 (~Q4)
D5-5: J8.3, U7.14 (~Q5)
D5-6: J8.7, U7.11 (~Q6)
D5-7: J8.8, U7.10 (~Q7)
D5-8: J8.5, U7.1 (~Q8)
D5-9: J8.6, U7.2 (~Q9)
D6-0: J9.1, U8.16 (~Q0)
D6-1: J9.2, U8.15 (~Q1)
D6-2: J9.9, U8.8 (~Q2)
D6-3: J9.10, U8.9 (~Q3)
D6-4: J9.4, U8.13 (~Q4)
D6-5: J9.3, U8.14 (~Q5)
D6-6: J9.7, U8.11 (~Q6)
D6-7: J9.8, U8.10 (~Q7)
D6-8: J9.5, U8.1 (~Q8)
D6-9: J9.6, U8.2 (~Q9)
GND: C5.2, C6.2, C7.2, C10.2, U6.12 (GND), U7.12 (GND), U8.12 (GND), U11.10 (VSS), U11.16 (A1), U11.17 (A2); also elsewhere on the board
I2C_SCL: U11.12 (SCK); also elsewhere on the board
I2C_SDA: U11.13 (SDA); also elsewhere on the board

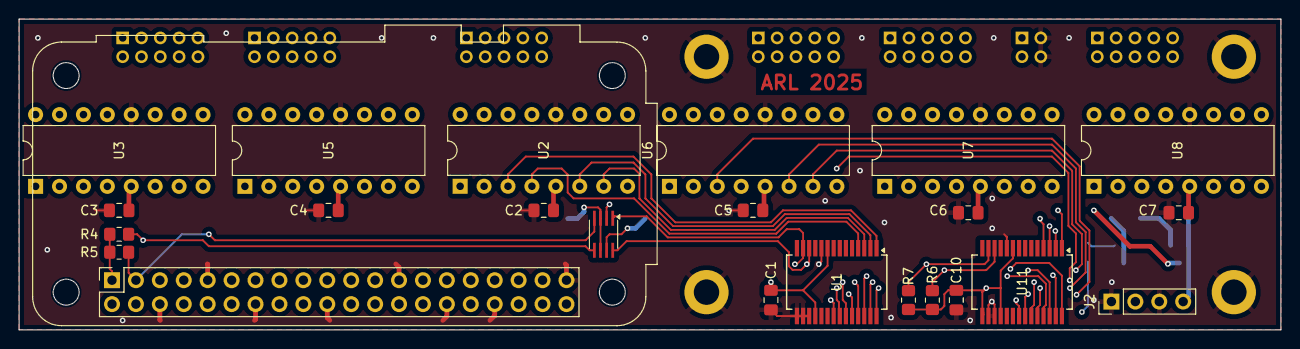
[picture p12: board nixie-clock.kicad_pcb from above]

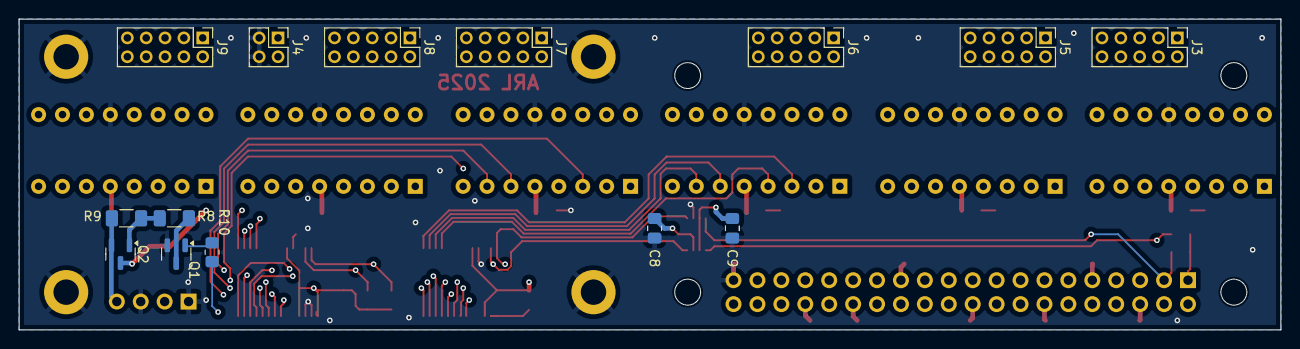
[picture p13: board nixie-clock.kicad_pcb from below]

Board: 4 copper layers, 134.0 x 33.0 mm, 41 parts (14 on the bottom side), 97 nets.

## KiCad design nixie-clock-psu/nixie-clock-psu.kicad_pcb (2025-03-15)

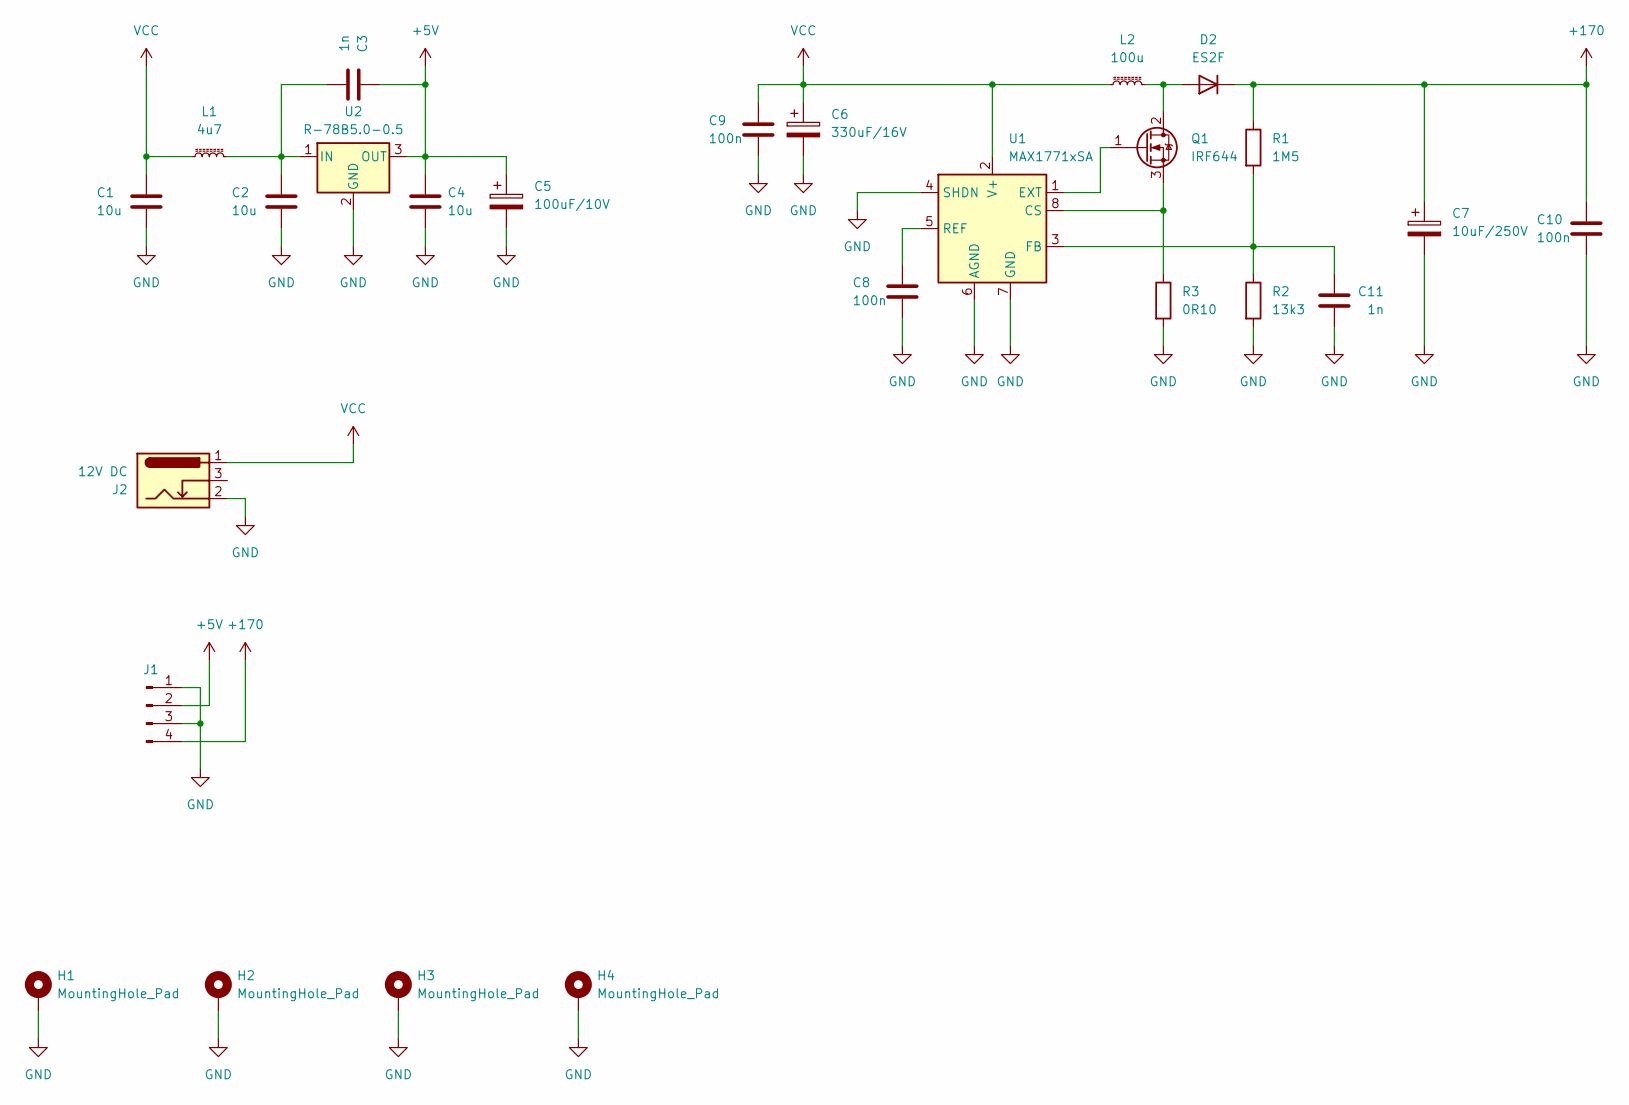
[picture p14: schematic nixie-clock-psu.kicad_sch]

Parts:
C1, C2, C4: 10u; C_0805_2012Metric_Pad1.18x1.45mm_HandSolder
C3, C11: 1n; C_0805_2012Metric_Pad1.18x1.45mm_HandSolder
C5: 100uF/10V; CP_Elec_5x5.3
C6: 330uF/16V; CP_Elec_6.3x7.7
C7: 10uF/250V; CP_Elec_10x12.5
C8, C9, C10: 100n; C_0805_2012Metric_Pad1.18x1.45mm_HandSolder
D2: ES2F; D_SMB
H1, H2, H3, H4: MountingHole_Pad; MountingHole_2.7mm_M2.5_DIN965_Pad
J1: Conn_01x04_Pin; PinSocket_1x04_P2.54mm_Vertical
J2: 12V DC; BarrelJack_GCT_DCJ200-10-A_Horizontal
L1: 4u7; L_Changjiang_FNR4030S
L2: 100u; L_Sunlord_SWPA8040S
Q1: IRF644; TO-263-2
R1: 1M5; R_1206_3216Metric
R2: 13k3; R_1206_3216Metric
R3: 0R10; R_1206_3216Metric
U1: MAX1771xSA; SO-8_3.9x4.9mm_P1.27mm
U2: R-78B5.0-0.5; 78xx-05A

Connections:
+5V: C3.2, C4.2, C5.1, J1.2, U2.3 (OUT)
+170: C7.1, C10.2, D2.1 (K), J1.4, R1.1
GND: C1.1, C2.1, C4.1, C5.2, C6.2, C7.2, C8.1, C9.1, C10.1, C11.1, H1.1, H2.1, H3.1, H4.1, J1.1, J1.3, J2.2, R2.2, R3.2, U1.4 (SHDN), U1.6 (AGND), U1.7 (GND), U2.2 (GND)
unnamed: D2.2 (A), L2.2, Q1.2 (D)
unnamed: Q1.1 (G), U1.1 (EXT)
unnamed: Q1.3 (S), R3.1, U1.8 (CS)
unnamed: C11.2, R1.2, R2.1, U1.3 (FB)
unnamed: C8.2, U1.5 (REF)
unnamed: C2.2, C3.1, L1.2, U2.1 (IN)
VCC: C1.2, C6.1, C9.2, J2.1, L1.1, L2.1, U1.2 (V+)

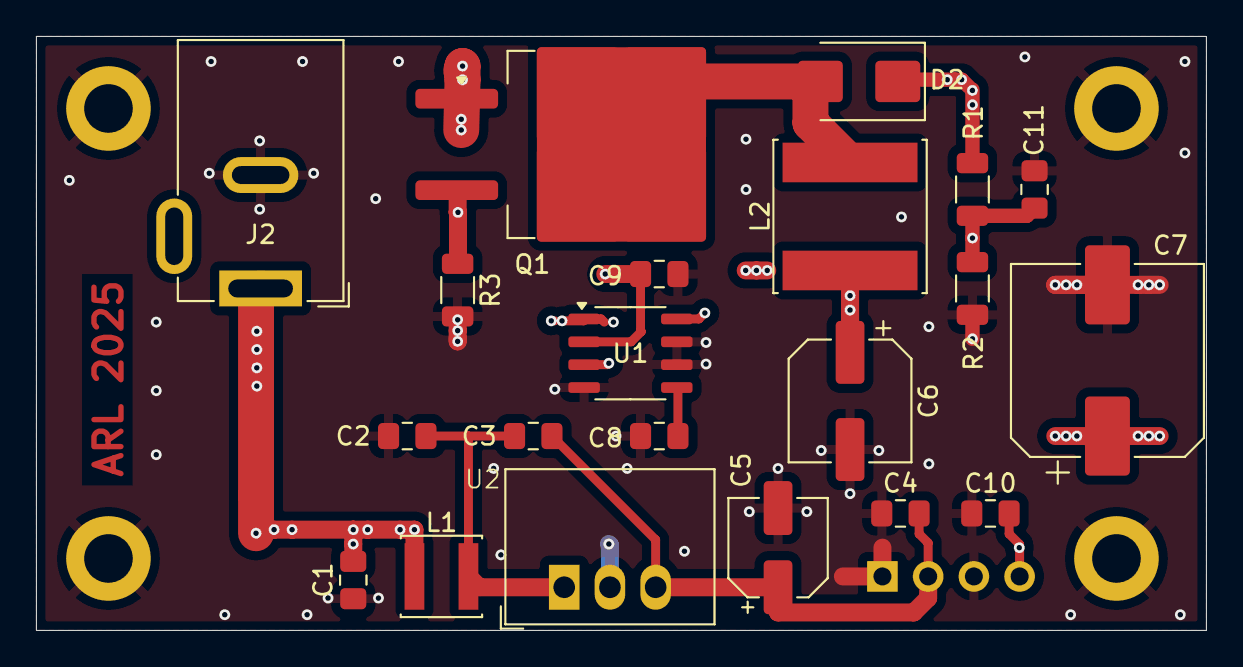
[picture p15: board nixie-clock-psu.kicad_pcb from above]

Board: 4 copper layers, 65.0 x 33.0 mm, 26 parts (1 on the bottom side), 10 nets.

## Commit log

2025-03-15 Added Kicad files
    [BOM-nixie-clock-psu.csv, BOM-nixie-clock-tubes.csv, BOM-nixie-clock.csv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]
2025-06-23 nixie-clock-tubes: Fix small layout issue
    [nixie-clock-tubes.kicad_pcb]
2025-06-23 nixie-bottom: Add files
    Add files for bottom lid PCB.
    [BOM-nixie-bottom.csv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]
2025-06-23 nixie-top: Add files
    Added files for top lid PCB.
    [BOM-nixie-top.csv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]
